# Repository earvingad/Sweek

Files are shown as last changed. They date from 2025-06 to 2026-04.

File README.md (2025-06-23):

# Sweek
Sweek is a Ferris/sweep inspired, 36 keys split keyboard.

The K in the name comes from it using [KMK](https://github.com/KMKfw/kmk_firmware).
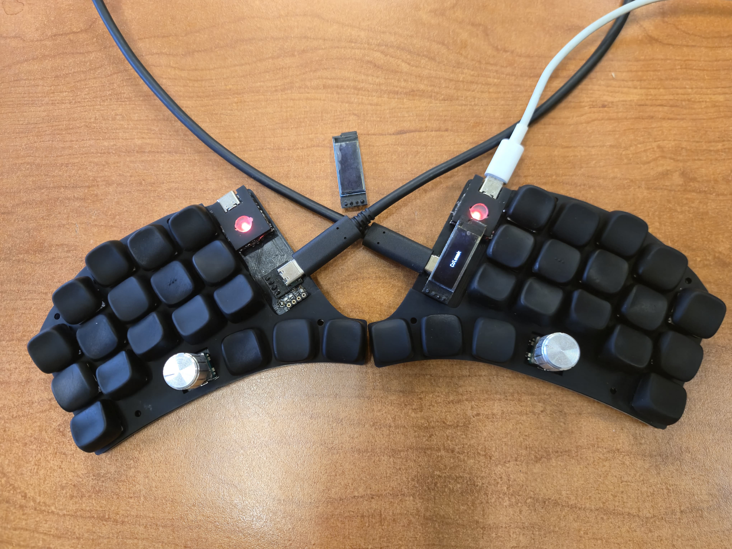
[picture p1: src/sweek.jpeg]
sweek

It features:
- Reversible PCB with through holes diodes for easy soldering.
- RP2040 as MCU.
- Support for MX, choc V1/V2 and Redragon low profile switches (I only tested MX and Redragon LP).
- EC11 encoders and oled displays.
- Communication is through USB-C (using a pair of small USB-C boards available, since I wanted as easiest to solder as possible).
- There is also a diodeless version.

Please see the [Building guide for v1.0.1](./src/buildingguide_v101.org).

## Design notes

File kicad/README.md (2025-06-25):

Here you can find the Kicad files to export the gerbers for production in JLCPCB or similar.

There are two versions:
1. sweek_rdmxchoc - Contains the files for the PCB that includes encoders and oled 128x32
2. sweek_rdmxchoc_diodless - Diodeless version, without encoders and oled.

Please see the [Building guide](/src/buildingguide_v101.org).

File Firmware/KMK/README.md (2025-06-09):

# Intructions for KMK

1. [Install Circuitpython](https://learn.adafruit.com/welcome-to-circuitpython/installing-circuitpython) to your RP2040-zero and then [KMK](https://github.com/KMKfw/kmk_firmware/blob/main/docs/en/Getting_Started.md#tldr-quick-start-guide). 
2. Rename the drives as `SWEEKL` and `SWEEKR`, respectively. Follow [this guide](https://learn.adafruit.com/welcome-to-circuitpython/renaming-circuitpy) to learn how to do it.
3. Follow the [Preparation guide for Display in KMK](https://github.com/KMKfw/kmk_firmware/blob/main/docs/en/Display.md#preparation) for the required libraries for the SSD1306 oled display.
4. Download the `neopixel.py` or `neopixel.mpy` from [here](https://github.com/adafruit/Adafruit_CircuitPython_NeoPixel/releases) and place it inside the `lib` folder of each RP2040-zero.
5. Copy the `code.py` to each RP2040-zero. It will automatically detect which half is which.

Enjoy!

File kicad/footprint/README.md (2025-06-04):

Custom footprint to support MX, choc V1/V2 and redragon Low Profile.

Created using:
- [Joe Scotto](https://github.com/joe-scotto/scottokeebs/tree/main/Extras/ScottoKicad) footprints for MX and choc and
- [rgoulter](https://github.com/rgoulter/keyboard-labs/blob/master/pcb/ProjectLocal.pretty/SW_Redragon_LowProfile_PCB_1.00u.kicad_mod) footprint for redragon Low Profile.

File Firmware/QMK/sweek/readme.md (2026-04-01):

# sweek

sweek

Sweek is a Ferris/sweep inspired, 36 keys split keyboard with encoders and OLED screens (although I have not configured OLED screens for QMK).

* Keyboard Maintainer: [earvingad](https://github.com/earvingad)
* Hardware Supported: [sweek](https://github.com/earvingad/sweek)

Compile with vial support and flash with EE_HANDS

    make sweek:vial:uf2-split-left

And then righ side:

    make sweek:vial:uf2-split-right

See the [build environment setup](https://docs.qmk.fm/#/getting_started_build_tools) and the [make instructions](https://docs.qmk.fm/#/getting_started_make_guide) for more information. Brand new to QMK? Start with our [Complete Newbs Guide](https://docs.qmk.fm/#/newbs).

## Bootloader

Enter the bootloader in 3 ways:

* **Physical reset button**: Press quickly twice the reset button from the RP2040-zero.
* **Bootmagic reset**: Hold down the key at (0,0) in the matrix (usually the top left key or Escape) and plug in the keyboard
* **Keycode in layout**: Press the key mapped to `QK_BOOT` if it is available

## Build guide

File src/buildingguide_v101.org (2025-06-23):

#+title: Sweek v1.0.1 building guide

Please do not consider this board suitable for beginners, you need some experience soldering as you will need to solder some jumpers. However, it is not difficult to solder. I recommend using enameled wire of 0.2-0.5 mm.

The board is reversible, but it needs to solder some jumpers for both sides to work correctly. I tried to avoid pin remapping in software as much as possible, but this means that jumpers need to be soldered differently in each side.

* Sweek with encoders and oled
** USB-C board, encoder and oled display
The communication is through an USB-C board like [[https://es.aliexpress.com/item/1005005187678366.html][this]]. The reason I chose this is because it is cheap and it is easy to solder.

Encoder height recommendation:

- For low profile switches use 10-12 mm tall EC11 encoders.
- For MX switches use 15 mm tall EC11 encoders.

Follow this picture as reference of how jumpers must solder. ALWAYS SOLDER FROM THE BACK OF THE PCB:

Use insulated tape to cover wires when needed. For example, in the right side, I would solder first Rx to D- and in order to avoid shorts, I would cover the jumper (Rx to D-) with insulation tape and then proceed to solder the 5.5 V jumper.
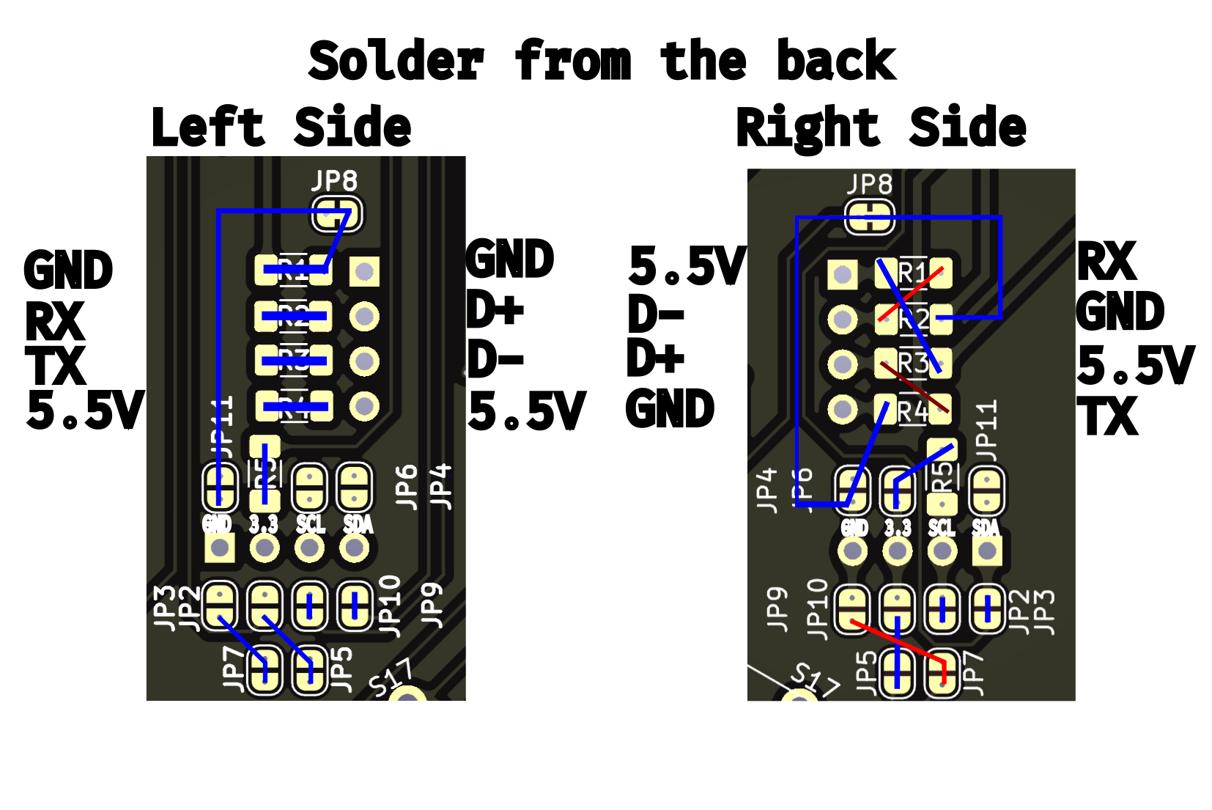
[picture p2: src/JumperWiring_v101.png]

** 3.3v ONLY ON THE RIGHT SIDE
Solder the jumper located on the MCU position (JP1). This will serve to route 3.3 V to the right oled display.
#+ATTR_HTML: :width 300px
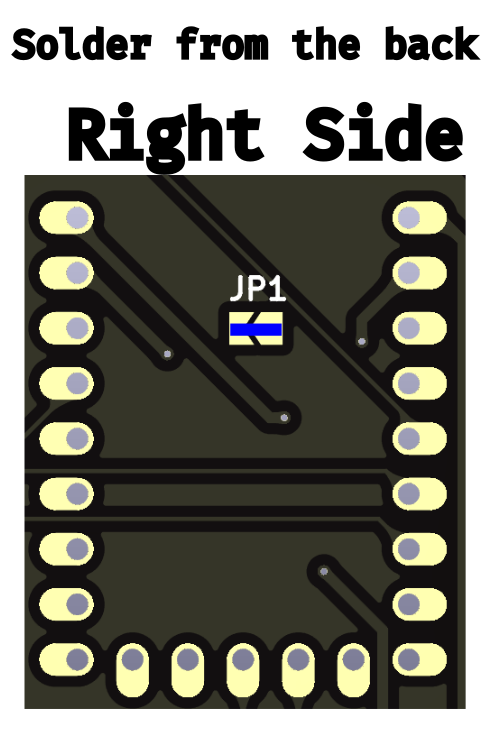
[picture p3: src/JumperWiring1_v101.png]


** MCU
In both sides, the RP2040 must always be facing up. This is how the PCB was designed in order to have the RGB led available as layer indicator and easy access to buttons for hard reset and enter boot mode.

Please be aware that pin 2 (GP2) is never in use, so *DO NOT SOLDER PIN 2 (GP2) OF THE RP2040 TO THE BOARD*.
** Diodes orientation
Solder diodes to the board, you can choose between SMD diodes (SOD-123) or through hole diodes, just make sure they are 1N4148

The board has printed the orientation, but take the following picture as reference. Ignore the MCU (I know it is not a RP2040 in the picture, I was experimenting).
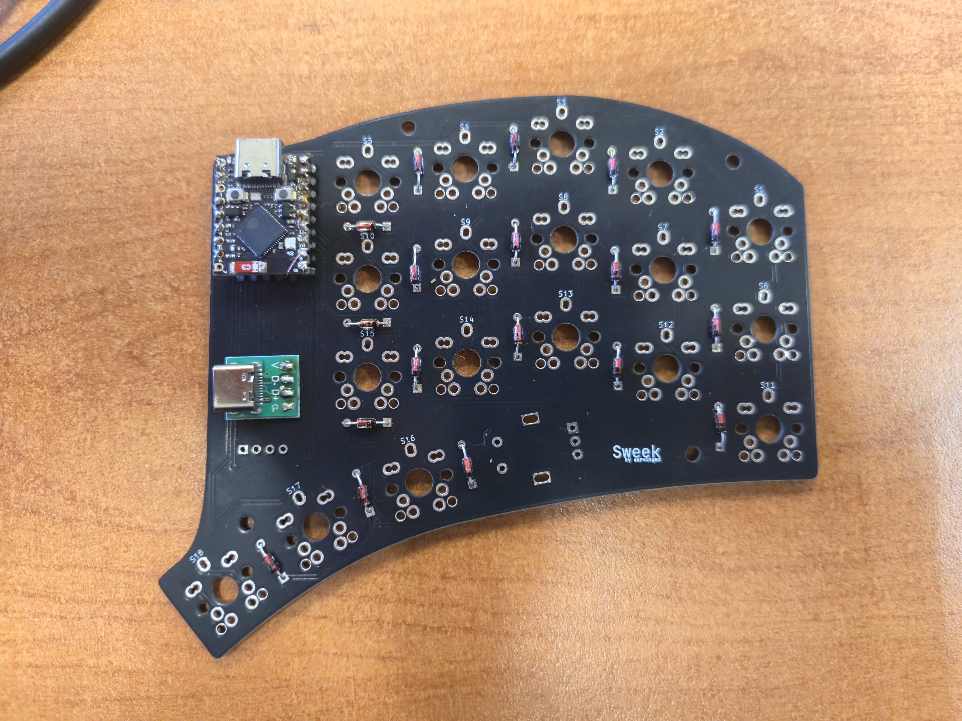
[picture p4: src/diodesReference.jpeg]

** Pin mapping
This is how pins are assigned to the columns and rows for each side:

Left side:
- Rows: GP29, GP28, GP27, GP26.
- Columns: GP3, GP4, GP5, GP6, GP7.

Right side:
- Rows: GP3, GP4, GP5, GP6.
- Columns: GP29, GP28, GP27, GP26, GP15.

Both sides:
- Encoder: GP10, GP9
- Encoder switch: GP11

Both sides:
- Oled SDA: GP12
- Oled SCL: GP13
* Diodeless version
** USB-C board
Solder according to the following picture.
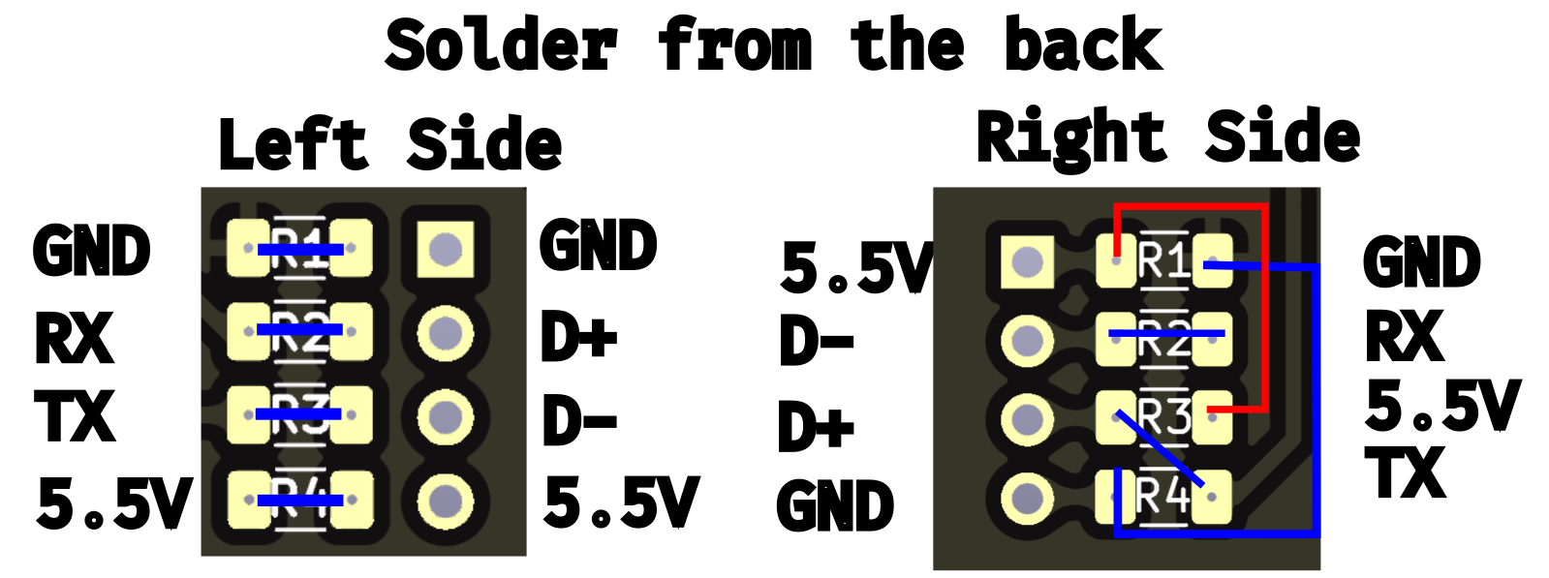
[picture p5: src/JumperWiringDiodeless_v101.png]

** JUMPERS
Compared to v1.0.0, in the new v1.0.1, the GND net is now part of the fill zone. In order to make it possible, two additional jumpers for GND and GP1 were added. Solder the GND and GP1 (RX) jumpers accordingly to each side.

ONLY ON RIGHT SIDE, solder the jumper located on the MCU position (JP1). This route the pin 2 (GP2) to switch-18 on the right side.
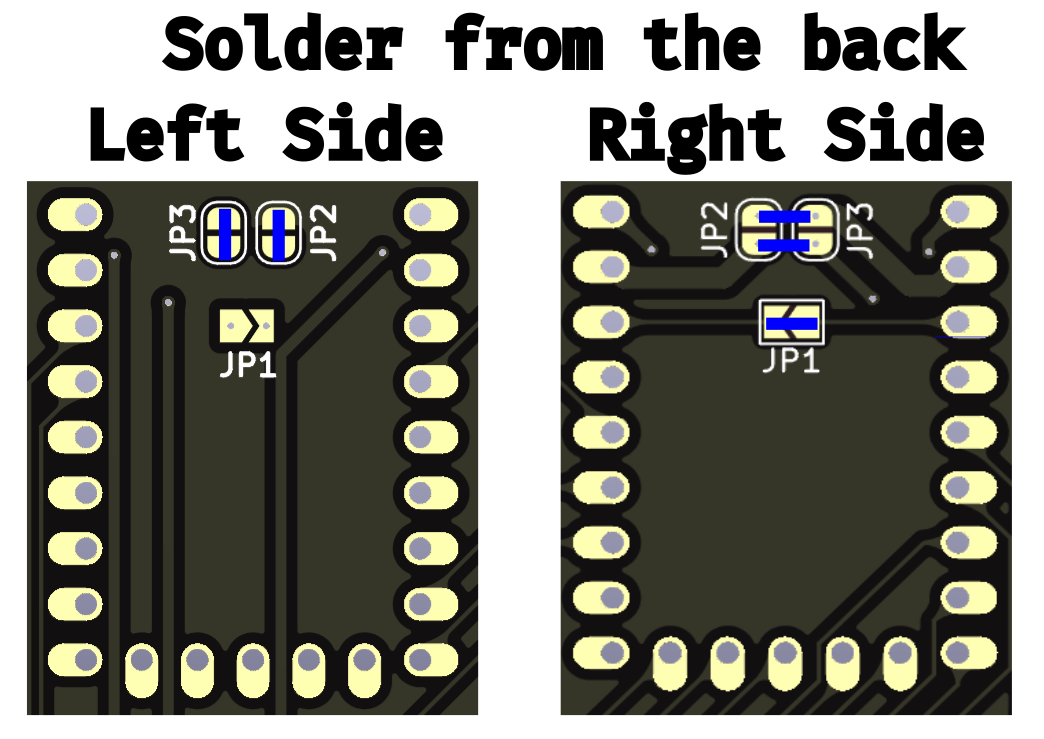
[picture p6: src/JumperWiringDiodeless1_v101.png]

** MCU
Solder every pin of the MCU (RP2040) to the board, except the 3.3 V pin.
** Pin to switch mapping
In both sides GP0 (TX) and GP1 (RX) are reserved for communication.

| Left side | Pin  | Switch | Right side | Pin  | Switch |
|-----------+------+--------+------------+------+--------|
|           | GP29 | S1     |            | GP3  | S1     |
|           | GP28 | S2     |            | GP4  | S2     |
|           | GP27 | S3     |            | GP5  | S3     |
|           | GP26 | S4     |            | GP6  | S4     |
|           | GP15 | S5     |            | GP7  | S5     |
|           | GP14 | S6     |            | GP8  | S6     |
|           | GP13 | S7     |            | GP9  | S7     |
|           | GP12 | S8     |            | GP10 | S8     |
|           | GP11 | S9     |            | GP11 | S9     |
|           | GP10 | S10    |            | GP12 | S10    |
|           | GP9  | S11    |            | GP13 | S11    |
|           | GP8  | S12    |            | GP14 | S12    |
|           | GP7  | S13    |            | GP15 | S13    |
|           | GP6  | S14    |            | GP26 | S14    |
|           | GP5  | S15    |            | GP27 | S15    |
|           | GP4  | S16    |            | GP28 | S16    |
|           | GP3  | S17    |            | GP29 | S17    |
|           | GP2  | S18    |            | GP2  | S18    |

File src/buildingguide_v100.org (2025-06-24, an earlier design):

#+title: Sweek v1.0.0 building guide

Please do not consider this board suitable for beginners, you need some experience soldering as you will need to solder some jumpers. However, it is not difficult to solder. I recommend using enameled wire of 0.2-0.5 mm.

The board is reversible, but it needs to solder some jumpers for both sides to work correctly. I tried to avoid pin remapping in software as much as possible, but this means that jumpers need to be soldered differently in each side.

* Sweek with encoders and oled
** USB-C board, encoder and oled display
The communication is through an USB-C board like [[https://es.aliexpress.com/item/1005005187678366.html][this]]. The reason I chose this is because it is cheap and it is easy to solder.

Encoder height recommendation:
- For low profile switches use 10-12 mm tall EC11 encoders.
- For MX switches use 15 mm tall EC11 encoders.

Follow this picture as reference of how jumpers must solder:

Use insulated tape to cover wires when needed. For example, in the right side, I would solder first Rx to D- and in order to avoid shorts, I would cover the jumper (Rx to D-) with insulation tape and then proceed to solder the 5.5 V jumper.
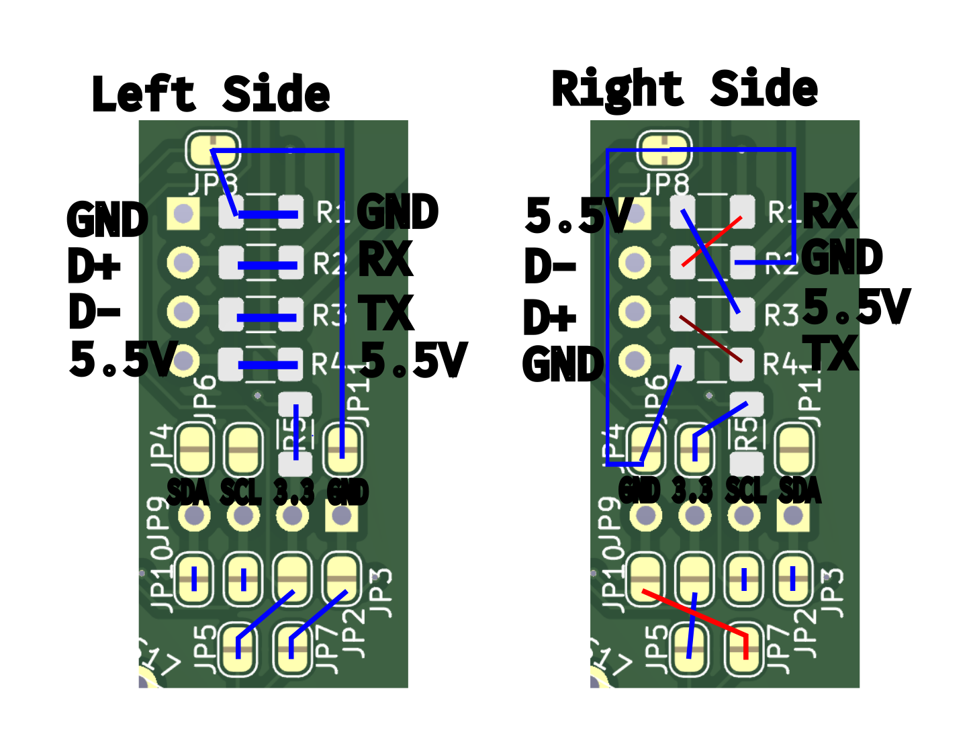
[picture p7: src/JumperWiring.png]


** 3.3v ONLY ON THE RIGHT SIDE
Solder the jumper located on the MCU position (JP1). This will serve to route 3.3 V to the right oled display.
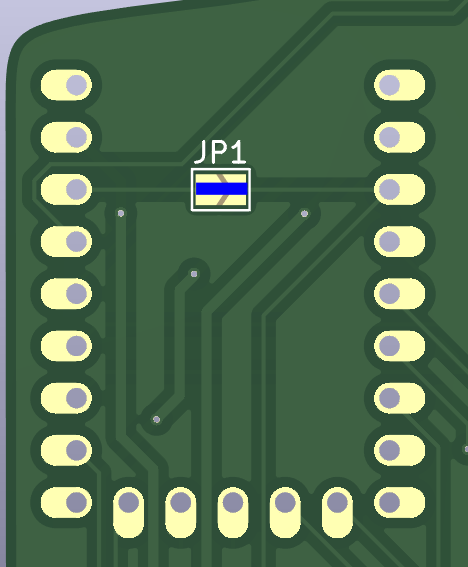
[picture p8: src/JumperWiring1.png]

** MCU
In both sides, the RP2040 must always be facing up. This is how the PCB was designed in order to have the RGB led available as layer indicator and easy access to buttons for hard reset and enter boot mode.

Please be aware that pin 2 (GP2) is never in use, so *DO NOT SOLDER PIN 2 (GP2) OF THE RP2040 TO THE BOARD*.
** Diodes orientation
Solder diodes to the board. The board has printed the orientation, but take the following picture as reference. Ignore the board (I know it is not a RP2040 in the picture, I was experimenting).

** Pin mapping
This is how pins are assigned to the columns and rows for each side:

Left side:
- Rows: GP29, GP28, GP27, GP26.
- Columns: GP3, GP4, GP5, GP6, GP7.

Right side:
- Rows: GP3, GP4, GP5, GP6.
- Columns: GP29, GP28, GP27, GP26, GP15.

Both sides:
- Encoder: GP10, GP9
- Encoder switch: GP11

Both sides:
- Oled SDA: GP12
- Oled SCL: GP13
* Diodeless version
** JUMPER ONLY ON THE RIGHT SIDE
Solder the jumper located on the MCU position (JP1). This route the pin 2 (GP2) to switch-18 on the right side.

** USB-C board
Solder according to the following picture.
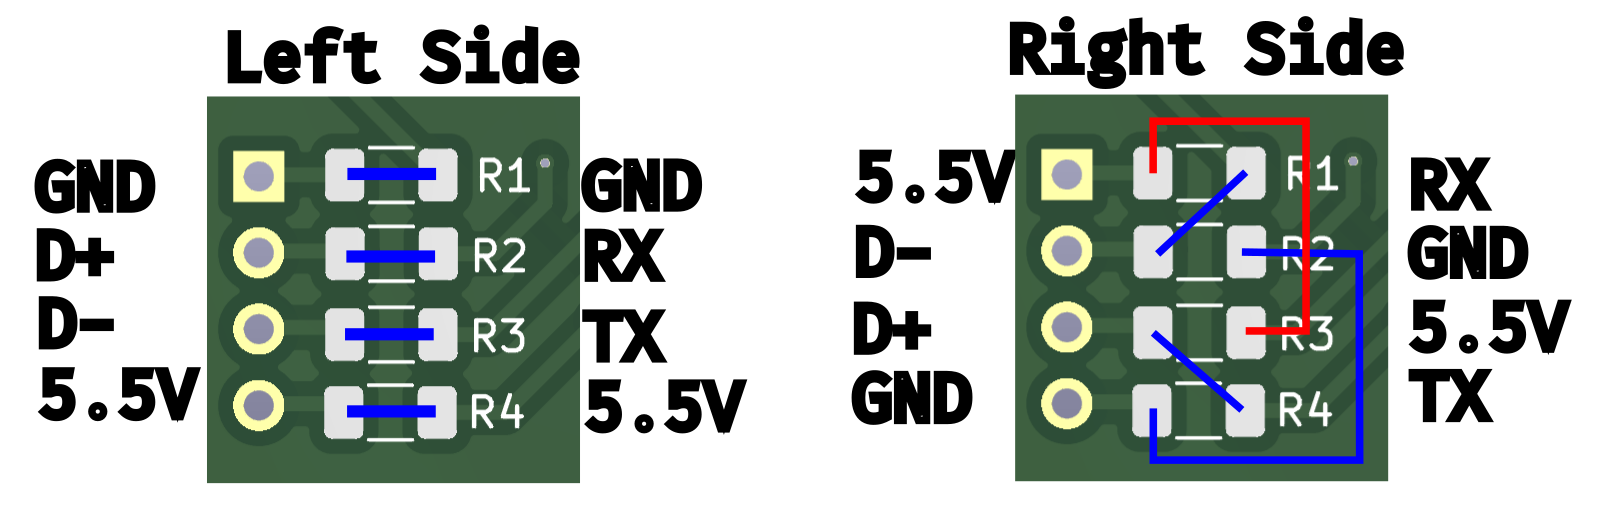
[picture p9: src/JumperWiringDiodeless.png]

** MCU
Solder every pin of the MCU (RP2040) except the 3.3 V pin.
** Pin to switch mapping
In both sides GP0 (TX) and GP1 (RX) are reserved for communication.

| Left side | Pin  | Switch | Right side | Pin  | Switch |
|-----------+------+--------+------------+------+--------|
|           | GP29 | S1     |            | GP3  | S1     |
|           | GP28 | S2     |            | GP4  | S2     |
|           | GP27 | S3     |            | GP5  | S3     |
|           | GP26 | S4     |            | GP6  | S4     |
|           | GP15 | S5     |            | GP7  | S5     |
|           | GP14 | S6     |            | GP8  | S6     |
|           | GP13 | S7     |            | GP9  | S7     |
|           | GP12 | S8     |            | GP10 | S8     |
|           | GP11 | S9     |            | GP11 | S9     |
|           | GP10 | S10    |            | GP12 | S10    |
|           | GP9  | S11    |            | GP13 | S11    |
|           | GP8  | S12    |            | GP14 | S12    |
|           | GP7  | S13    |            | GP15 | S13    |
|           | GP6  | S14    |            | GP26 | S14    |
|           | GP5  | S15    |            | GP27 | S15    |
|           | GP4  | S16    |            | GP28 | S16    |
|           | GP3  | S17    |            | GP29 | S17    |
|           | GP2  | S18    |            | GP2  | S18    |

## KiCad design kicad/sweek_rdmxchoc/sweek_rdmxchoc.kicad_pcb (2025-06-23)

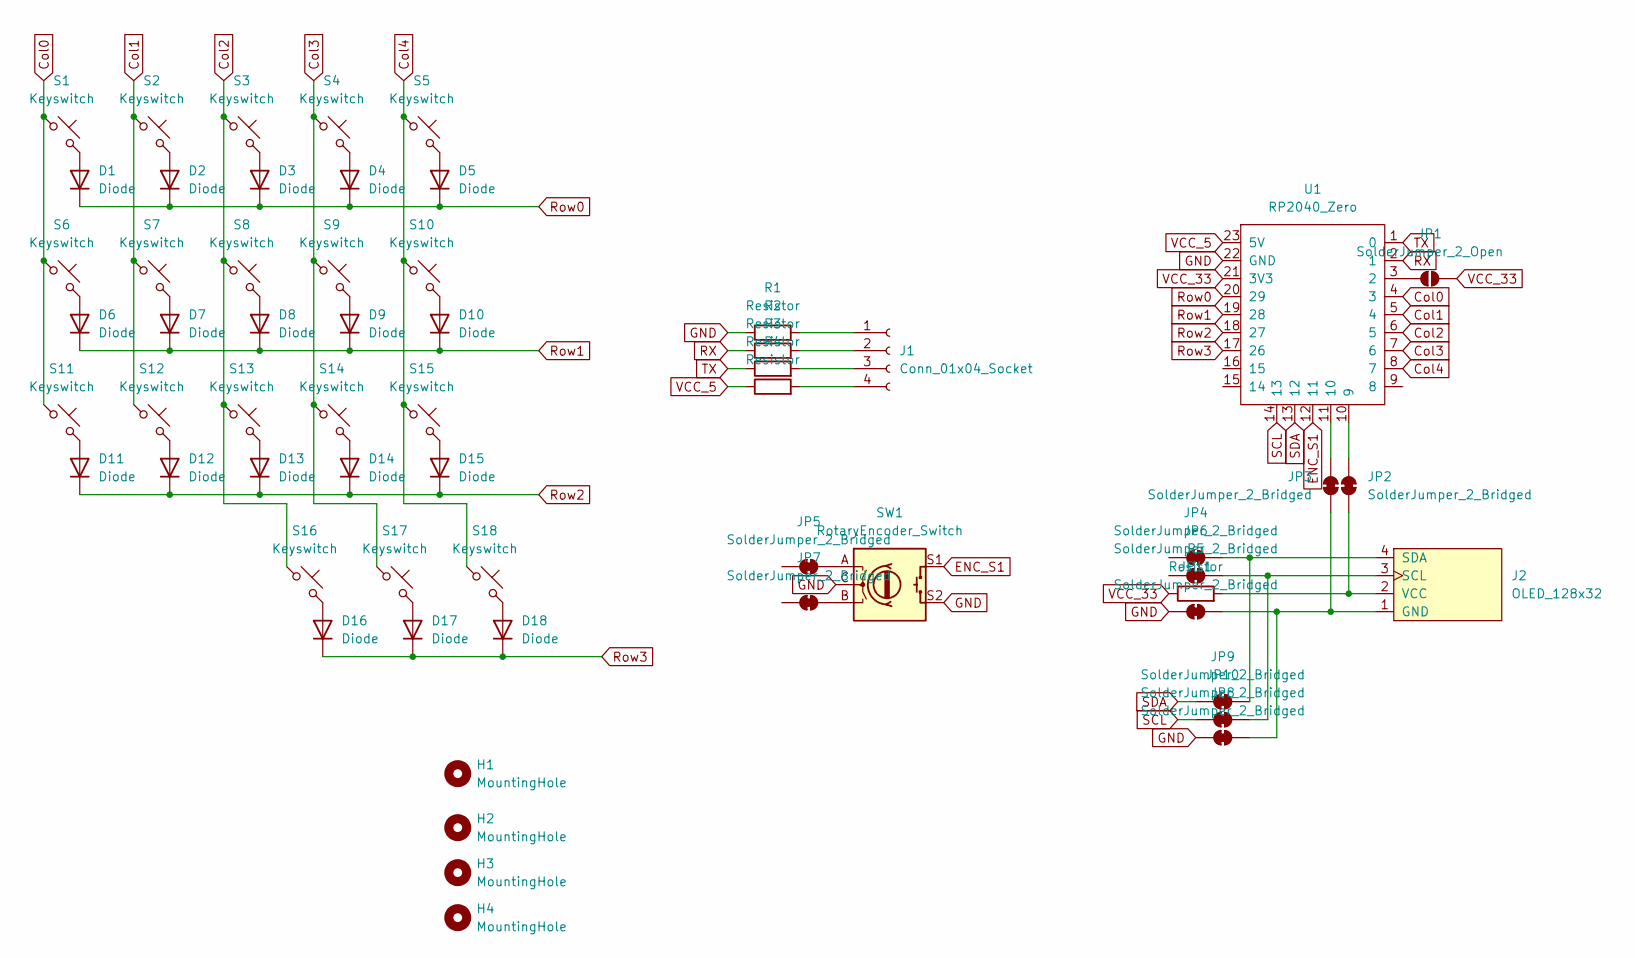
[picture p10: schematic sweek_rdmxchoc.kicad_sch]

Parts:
D1, D2, D3, D4, D5, D6, D7, D8, D9, D10, D11, D12, D13, D14, D15, D16, D17, D18: Diode; Diode_DO-35_SOD-123
H1, H2, H3, H4: MountingHole; MountingHole_2.7mm_M2.5
J1: Conn_01x04_Socket; USB_C_board
J2: OLED_128x32
JP1: SolderJumper_2_Open; SolderJumper-2_P1.3mm_Open_TrianglePad1.0x1.5mm_custom
JP2, JP3, JP4, JP5, JP6, JP7, JP9, JP10, JP11: SolderJumper_2_Bridged; SolderJumper-2_P1.3mm_Open_RoundedPad1.0x1.5mm_custom
JP8: SolderJumper_2_Bridged; SolderJumper-2_P1.3mm_Bridged_RoundedPad1.0x1.5mm_custom
R1, R2, R3, R4, R5: Resistor; R_1206_3216Metric_Pad1.30x1.75mm_custom
S1, S2, S3, S4, S5, S6, S7, S8, S9, S10, S11, S12, S13, S14, S15, S16, S17, S18: Keyswitch; RD_MX_Choc_V1V2_1.00u
SW1: RotaryEncoder_Switch; RotaryEncoder_Alps_EC11E-Switch_Vertical_H20mm
U1: RP2040_Zero

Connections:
Col0: S1.1, S6.1, S11.1, U1.4 (3)
Col1: S2.1, S7.1, S12.1, U1.5 (4)
Col2: S3.1, S8.1, S13.1, S16.1, U1.6 (5)
Col3: S4.1, S9.1, S14.1, S17.1, U1.7 (6)
Col4: S5.1, S10.1, S15.1, S18.1, U1.8 (7)
ENC_S1: SW1.S1, U1.12 (11)
GND: JP8.2 (B), JP11.2 (B), R1.1, SW1.C, SW1.S2, U1.22 (GND)
unnamed: D1.2 (A), S1.2
unnamed: D2.2 (A), S2.2
unnamed: D3.2 (A), S3.2
unnamed: D4.2 (A), S4.2
unnamed: D5.2 (A), S5.2
unnamed: D6.2 (A), S6.2
unnamed: D7.2 (A), S7.2
unnamed: D8.2 (A), S8.2
unnamed: D9.2 (A), S9.2
unnamed: D10.2 (A), S10.2
unnamed: D11.2 (A), S11.2
unnamed: D12.2 (A), S12.2
unnamed: D13.2 (A), S13.2
unnamed: D14.2 (A), S14.2
unnamed: D15.2 (A), S15.2
unnamed: D16.2 (A), S16.2
unnamed: D17.2 (A), S17.2
unnamed: D18.2 (A), S18.2
unnamed: J1.1, R1.2
unnamed: J1.2, R2.2
unnamed: J1.3, R3.2
unnamed: J1.4, R4.2
unnamed: J2.1 (GND), JP3.1 (A), JP8.1 (A), JP11.1 (A)
unnamed: J2.3 (SCL), JP6.1 (A), JP10.2 (B)
unnamed: J2.4 (SDA), JP4.2 (B), JP9.2 (B)
unnamed: J2.2 (VCC), JP2.1 (A), R5.2
unnamed: JP1.1 (A), U1.3 (2)
unnamed: JP2.2 (B), U1.10 (9)
unnamed: JP3.2 (B), U1.11 (10)
unnamed: JP5.2 (B), SW1.A
unnamed: JP7.2 (B), SW1.B
RX: R2.1, U1.2 (1)
Row0: D1.1 (K), D2.1 (K), D3.1 (K), D4.1 (K), D5.1 (K), U1.20 (29)
Row1: D6.1 (K), D7.1 (K), D8.1 (K), D9.1 (K), D10.1 (K), U1.19 (28)
Row2: D11.1 (K), D12.1 (K), D13.1 (K), D14.1 (K), D15.1 (K), U1.18 (27)
Row3: D16.1 (K), D17.1 (K), D18.1 (K), U1.17 (26)
SCL: JP10.1 (A), U1.14 (13)
SDA: JP9.1 (A), U1.13 (12)
TX: R3.1, U1.1 (0)
VCC_5: R4.1, U1.23 (5V)
VCC_33: JP1.2 (B), R5.1, U1.21 (3V3)

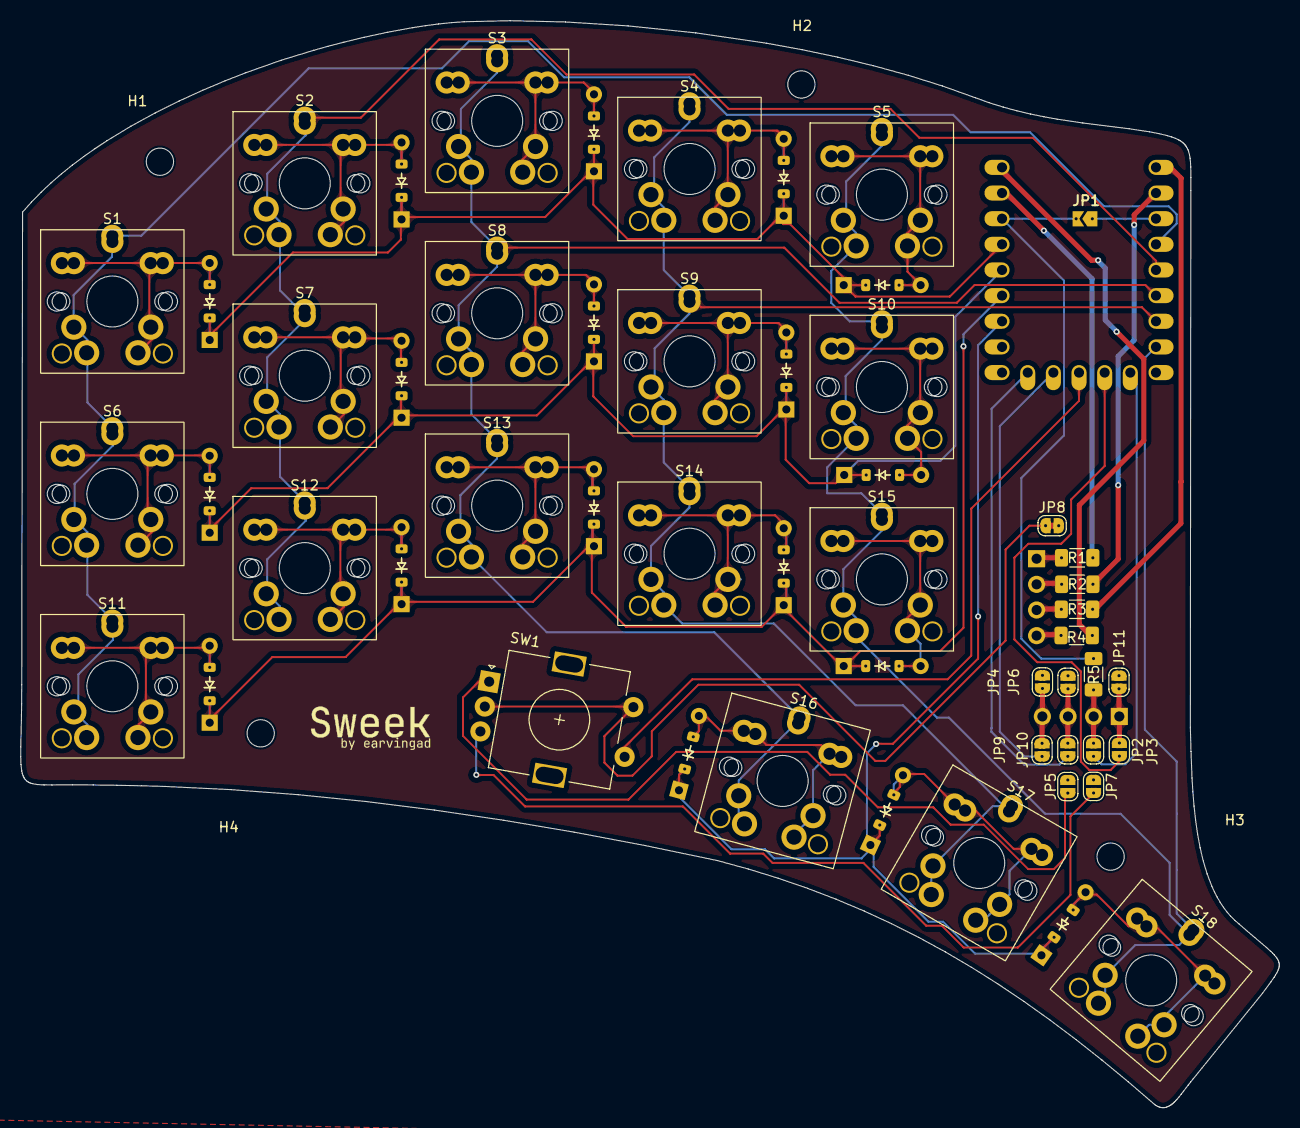
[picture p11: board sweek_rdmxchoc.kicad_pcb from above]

Board: 2 copper layers, 124.6 x 107.6 mm, 60 parts (1 on the bottom side), 48 nets.

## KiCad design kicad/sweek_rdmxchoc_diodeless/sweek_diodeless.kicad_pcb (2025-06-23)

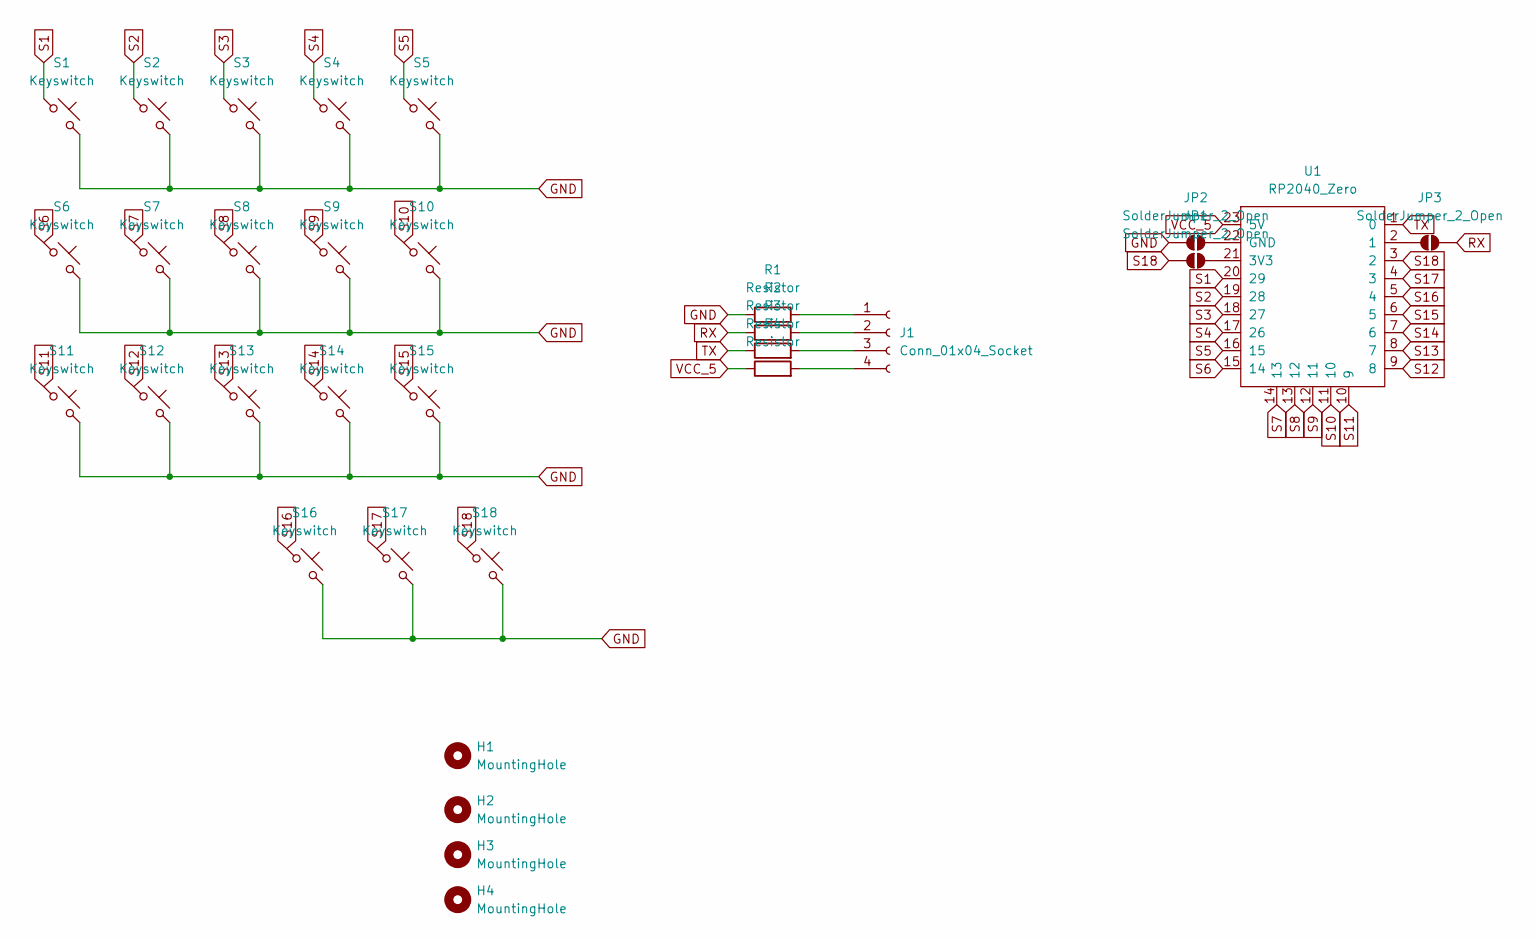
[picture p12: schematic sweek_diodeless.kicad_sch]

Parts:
H1, H2, H3, H4: MountingHole; MountingHole_2.7mm_M2.5
J1: Conn_01x04_Socket; USB_C_board
JP1: SolderJumper_2_Open; SolderJumper-2_P1.3mm_Open_TrianglePad1.0x1.5mm_custom
JP2, JP3: SolderJumper_2_Open; SolderJumper-2_P1.3mm_Open_RoundedPad1.0x1.5mm_custom
R1, R2, R3, R4: Resistor; R_1206_3216Metric_Pad1.30x1.75mm_custom
S1, S2, S3, S4, S5, S6, S7, S8, S9, S10, S11, S12, S13, S14, S15, S16, S17, S18: Keyswitch; RD_MX_Choc_V1V2_1.00u
U1: RP2040_Zero

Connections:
GND: JP2.1 (A), R1.1, S1.2, S2.2, S3.2, S4.2, S5.2, S6.2, S7.2, S8.2, S9.2, S10.2, S11.2, S12.2, S13.2, S14.2, S15.2, S16.2, S17.2, S18.2
unnamed: J1.1, R1.2
unnamed: J1.2, R2.2
unnamed: J1.3, R3.2
unnamed: J1.4, R4.2
unnamed: JP1.2 (B), U1.21 (3V3)
unnamed: JP2.2 (B), U1.22 (GND)
unnamed: JP3.1 (A), U1.2 (1)
RX: JP3.2 (B), R2.1
S1: S1.1, U1.20 (29)
S2: S2.1, U1.19 (28)
S3: S3.1, U1.18 (27)
S4: S4.1, U1.17 (26)
S5: S5.1, U1.16 (15)
S6: S6.1, U1.15 (14)
S7: S7.1, U1.14 (13)
S8: S8.1, U1.13 (12)
S9: S9.1, U1.12 (11)
S10: S10.1, U1.11 (10)
S11: S11.1, U1.10 (9)
S12: S12.1, U1.9 (8)
S13: S13.1, U1.8 (7)
S14: S14.1, U1.7 (6)
S15: S15.1, U1.6 (5)
S16: S16.1, U1.5 (4)
S17: S17.1, U1.4 (3)
S18: JP1.1 (A), S18.1, U1.3 (2)
TX: R3.1, U1.1 (0)
VCC_5: R4.1, U1.23 (5V)

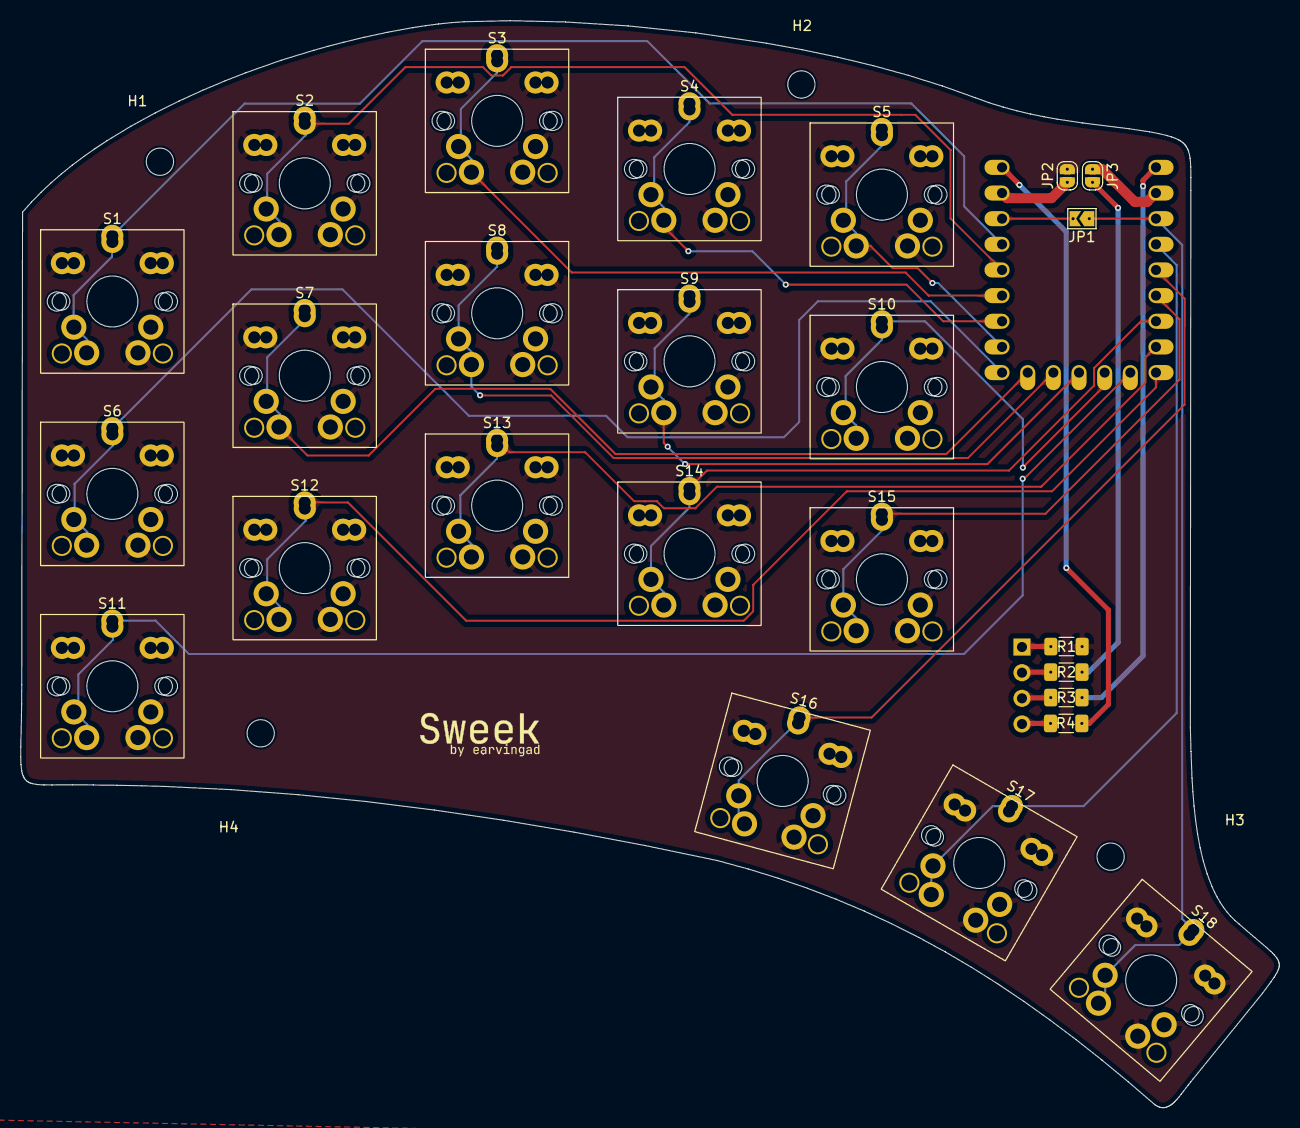
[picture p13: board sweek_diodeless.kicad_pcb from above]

Board: 2 copper layers, 124.6 x 107.6 mm, 31 parts (0 on the bottom side), 29 nets.

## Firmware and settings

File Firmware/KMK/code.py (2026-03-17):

print("Starting sweek.")

import board
from kmk.kmk_keyboard import KMKKeyboard
from kmk.keys import KC
from kmk.scanners import DiodeOrientation
from kmk.scanners.keypad import KeysScanner, MatrixScanner
from kmk.scanners.encoder import RotaryioEncoder
from kmk.modules.mouse_keys import MouseKeys
from kmk.modules.combos import Combos, Chord
from kmk.modules.holdtap import HoldTap
from kmk.modules.sticky_keys import StickyKeys
from kmk.modules.capsword import CapsWord
from kmk.modules.layers import Layers
from kmk.extensions.international import International
from kmk.modules.split import Split, SplitSide, SplitType
from kmk.extensions.media_keys import MediaKeys
from kmk.modules.mouse_jiggler import MouseJiggler
from kmk.modules.sticky_mod import StickyMod

# side = SplitSide.LEFT
# side = SplitSide.RIGHT
from storage import getmount
side = SplitSide.RIGHT if str(getmount('/').label)[-1] == 'R' else SplitSide.LEFT

split = Split(
    split_flip=True,  # If both halves are the same, but flipped, set this True
    split_side=None,  # Sets if this is to SplitSide.LEFT or SplitSide.RIGHT, or use EE hands
    split_type=SplitType.UART,  # Defaults to UART
    split_target_left=False,  # Assumes that left will be the one on USB. Set to False if it will be the right
    uart_interval=20,  # Sets the uarts delay. Lower numbers draw more power
    data_pin=board.GP1,  # The primary data pin to talk to the secondary device with
    data_pin2=board.GP0,  # Second uart pin to allow 2 way communication
    uart_flip=False,  # Reverses the RX and TX pins if both are provided
    use_pio=False,  # Use RP2040 PIO implementation of UART. Required if you want to use other pins than RX/TX
)

if side == SplitSide.RIGHT:
    row_pins = (board.GP3 , board.GP4 , board.GP5 , board.GP6)
    col_pins = (board.GP29, board.GP28, board.GP27, board.GP26, board.GP15)
else:
    row_pins = (board.GP29, board.GP28, board.GP27, board.GP26)
    col_pins = (board.GP3 , board.GP4 , board.GP5 , board.GP6, board.GP7)

enca=board.GP10
encb=board.GP9
encs=[board.GP11]

class MyKeyboard(KMKKeyboard):
    def __init__(self):
        super().__init__()
        # create and register the scanner
        self.matrix = [
            MatrixScanner(
            # required arguments:
            row_pins=row_pins,
            column_pins=col_pins,
                ),
            RotaryioEncoder(
            # require argument:
            pin_a=enca,
            pin_b=encb,
            divisor=4,
                ),
            KeysScanner(
            # require argument:
            pins=encs,
            value_when_pressed=False,
            pull=True,
                ),
        ]
        self.coord_mapping = [
                0, 1, 2, 3, 4,   27, 26, 25, 24, 23,
                5, 6, 7, 8, 9,   32, 31, 30, 29, 28,
                10,11,12,13,14,  37, 36, 35, 34, 33,
                15,16,17,18,19,  42, 41, 40, 39, 38,
                      20,21,22,  45, 44, 43 ]

keyboard = MyKeyboard()
keyboard.diode_orientation = DiodeOrientation.COL2ROW

mousekeys = MouseKeys(
    max_speed = 30,
    acc_interval = 20, # Delta ms to apply acceleration
    move_step = 1
)

combos = Combos()
holdtap = HoldTap()
holdtap.tap_time = 200
sticky_keys = StickyKeys(release_after=500)
caps_word = CapsWord()
sticky_mod = StickyMod()
keyboard.modules.append(Layers())
keyboard.modules.append(combos)
keyboard.modules.append(holdtap)
keyboard.modules.append(mousekeys)
keyboard.modules.append(caps_word)
keyboard.modules.append(sticky_keys)
keyboard.extensions.append(International())
keyboard.extensions.append(MediaKeys())
keyboard.modules.append(jiggler)
keyboard.modules.append(sticky_mod)
keyboard.modules.append(split)

try:
    import busio
    from kmk.extensions.display import Display, TextEntry
    # For SSD1306
    from kmk.extensions.display.ssd1306 import SSD1306
    # Replace SCL and SDA according to your hardware configuration.
    i2c_bus = busio.I2C(board.GP13, board.GP12)
    driver = SSD1306(
        # Mandatory:
        i2c=i2c_bus,
        # Optional:
        device_address=0x3C,
        )
    display = Display(
        display=driver,
        entries=[
            TextEntry(text="Colemak" , x=40, y=13, layer=0),
            TextEntry(text="Mouse"   , x=40, y=13, layer=1),
            TextEntry(text="Numbers" , x=40, y=13, layer=2),
            TextEntry(text="Function", x=40, y=13, layer=3),
            TextEntry(text="Symbols" , x=40, y=13, layer=4),
            TextEntry(text="Extras"  , x=40, y=13, layer=5),
            TextEntry(text=" Sweek " , x=40, y=13, inverted=True, layer=6),
        ],
        #Optional width argument. Default is 128.
        width=128,
        height=32,
    )
    keyboard.extensions.append(display)
except:
    pass

import neopixel
pixel_pin = board.GP16
num_pixels = 1

pixels = neopixel.NeoPixel(pixel_pin, num_pixels, brightness=0.3, auto_write=False)
RED = (55, 0, 0)
GREEN = (0, 55, 0)
BLUE = (0, 0, 55)
YELLOW = (55, 55, 0)
CYAN = (0, 55, 55)
PURPLE = (55, 0, 55)
WHITE = (55, 55, 55)

def on_layer_change(self, layer):
    if layer == 0:
        pixels.fill(RED)
    elif layer == 1:
        pixels.fill(BLUE)
    elif layer == 2:
        pixels.fill(GREEN)
    elif layer == 3:
        pixels.fill(WHITE)
    elif layer == 4:
        pixels.fill(PURPLE)
    elif layer == 5:
        pixels.fill(CYAN)
    elif layer == 6:
        pixels.fill(CYAN)
    # update the LEDs manually if no animation is active:
    pixels.show()

class RGBLayers(Layers):
    def during_bootup(self, sandbox):
        layer=keyboard.active_layers[0]
        on_layer_change(self, layer)

    def activate_layer(self, keyboard, layer, idx=None):
        super().activate_layer(keyboard, layer, idx)
        on_layer_change(self, layer)

    def deactivate_layer(self, keyboard, layer):
        super().deactivate_layer(keyboard, layer)
        layer=keyboard.active_layers[0]
        on_layer_change(self, layer)

keyboard.modules.append(RGBLayers())

SPC_ALT  = KC.HT(KC.SPC , KC.SK(KC.LALT), tap_interrupted=True)
DOT_APP  = KC.HT(KC.DOT , KC.APP        , tap_interrupted=True)
BSPC_ALT = KC.HT(KC.BSPC, KC.RALT       , tap_interrupted=True)

SK_LGUI = KC.SK(KC.LGUI)
SK_LCTL = KC.SK(KC.LCTL)
SK_RALT = KC.SK(KC.RALT)
NXT_WIN = KC.SM(KC.TAB, KC.LALT)
PRV_WIN = KC.SM(KC.TAB, KC.LSFT(KC.LALT))

SK_RSFT = KC.SK(KC.RSFT)
R_L1    = KC.HT(KC.R  , KC.MO(1), tap_interrupted=True)
S_L2    = KC.HT(KC.S  , KC.MO(2), tap_interrupted=True)
T_L3    = KC.HT(KC.T  , KC.MO(3), tap_interrupted=True)
N_L6    = KC.HT(KC.N  , KC.MO(6), tap_interrupted=True)
E_L4    = KC.HT(KC.E  , KC.MO(4), tap_interrupted=True)
ENT_L5  = KC.HT(KC.ENT, KC.MO(5))
ESC_L5  = KC.HT(KC.ESC, KC.MO(5))

ALT_F4  = KC.LALT(KC.F4)
CTL_ALT = KC.LCTL(KC.LALT)
CTLALTD = KC.LCTL(KC.LALT(KC.DEL))
CTLSFTT = KC.LCTL(KC.LSFT(KC.T))
LSFTDEL = KC.LSFT(KC.DEL)

_______ = KC.TRNS
XXXXXXX = KC.NO

combos.combos = [
    Chord((KC.W, KC.F), KC.TAB),
    Chord((KC.F, KC.P), KC.CW),
    Chord((KC.O, KC.Y), KC.DEL),
    Chord((KC.O, KC.L), KC.LBRC),
    ]

keyboard.keymap =  [
    [ # 0 COLEMAK
        KC.Q    , KC.W    , KC.F    , KC.P    , KC.G   ,              KC.J     , KC.L      , KC.O      , KC.Y      , KC.SCLN ,
        KC.A    , R_L1    , S_L2    , T_L3    , KC.D   ,              KC.H     , N_L6      , E_L4      , KC.I      , KC.U    ,
        KC.Z    , KC.X    , KC.C    , KC.V    , KC.B   ,              KC.K     , KC.M      , KC.COMMA  , DOT_APP   , KC.SLSH ,
        XXXXXXX , XXXXXXX , KC.LCTL , SPC_ALT , ESC_L5 ,              ENT_L5   , BSPC_ALT  , SK_RSFT   , XXXXXXX   , XXXXXXX ,
                            KC.DOWN , KC.UP   , KC.ENT ,              KC.ENT   , KC.LEFT   , KC.RIGHT  ,
    ],
    [ # 1 Mouse
        _______ , _______ , _______ , _______ , _______ ,             _______  , KC.MB_LMB , KC.MW_UP  , KC.MB_RMB , _______  ,
        _______ , _______ , KC.MB_LMB,_______ ,KC.MB_RMB,             _______  , KC.MS_LT  , KC.MS_DN  , KC.MS_UP  , KC.MS_RT ,
        _______ , _______ , _______ , _______ , _______ ,             _______  , KC.MB_MMB , KC.MW_DN  , _______   , _______  ,
        XXXXXXX , XXXXXXX , _______ , KC.SPC  , _______ ,             _______  , _______   , _______   , XXXXXXX   , XXXXXXX  ,
                           KC.LEFT  , KC.RIGHT, _______ ,             _______  , KC.LSFT(KC.TAB) , KC.TAB,
    ],
    [ # 2 Right Numbers/Shift symbols
        _______ , KC.UP   , _______ , _______ , _______ ,             KC.PPLS   , KC.N7     , KC.N8     , KC.N9    , KC.PAST  ,
        _______ , KC.LEFT , _______ , KC.RIGHT, _______ ,             KC.PMNS   , KC.N4     , KC.N5     , KC.N6    , KC. DOT  ,
        _______ , KC.DOWN , _______ , KC.COMMA, _______ ,             KC.N0     , KC.N1     , KC.N2     , KC.N3    , KC.PSLS  ,
        XXXXXXX , XXXXXXX , _______ , _______ , _______ ,             _______   , _______   , _______   , XXXXXXX  , XXXXXXX  ,
                            _______ , _______ , _______ ,             KC.LCTL(KC.N0)        , KC.LCTL(KC.MW_DN) , KC.LCTL(KC.MW_UP)  , 
    ],
    [ # 3 Function keys
        KC.RLD  , PRV_WIN , NXT_WIN , _______ , _______ ,             _______  , KC.F7     , KC.F8     , KC.F9     , KC.F10   ,
        ALT_F4  , CTLSFTT , LSFTDEL , _______ , _______ ,             _______  , KC.F4     , KC.F5     , KC.F6     , KC.F11   ,
        KC.RESET, CTL_ALT , CTLALTD , _______ , _______ ,             _______  , KC.F1     , KC.F2     , KC.F3     , KC.F12   ,
        XXXXXXX , XXXXXXX , _______ , _______ , _______ ,             _______  , _______   , _______   , XXXXXXX   , XXXXXXX  ,
                            _______ , _______ , _______ ,             KC.MPLY  , KC.VOLD   , KC.VOLU   , 
    ],
    [ # 4 Left Symbols
        KC.EXLM , KC.AT   , KC.HASH , KC.DLR  , KC.PERC ,             KC.CIRC  , KC.AMPR   , _______   , KC.GRV    , _______  ,
        KC.MINS , KC.EQL  , KC.LBRC , KC.QUOT , KC.BSLS ,             KC.ASTR  , KC.LPRN   , _______   , KC.RPRN   , _______  ,
        KC.PLUS , KC.UNDS , KC.RBRC , KC.RCBR , KC.PIPE ,             _______  , KC.NUBS   , _______   , _______   , _______  ,
        XXXXXXX , XXXXXXX , _______ , _______ , _______ ,             KC.RCTL  , _______   , _______   , XXXXXXX   , XXXXXXX  ,
         KC.LSFT(KC.LEFT) , KC.LSFT(KC.RIGHT) , _______ ,             _______  , _______   , _______   , 
    ],
    [ # 5 Nav/extras
        KC.CAPS , KC.HOME , KC.PGUP , KC.DEL  , KC.LSFT ,             _______  , _______   , KC.PGUP   ,  KC.HOME  ,  _______     ,
        KC.LEFT , KC.DOWN , KC.UP   , KC.RIGHT, SK_LGUI ,             KC.TG(1) , KC.BSPC   , _______   ,  _______  ,  KC.MJ_START ,
        _______ , KC.END  , KC.PGDN , KC.BSPC , KC.ENT  ,             KC.TG(6) , _______   , KC.PGDN   ,  KC.END   ,  KC.MJ_STOP  ,
        XXXXXXX , XXXXXXX , _______ , _______ , _______ ,             _______  , _______   , _______   ,  XXXXXXX  ,  XXXXXXX     ,
                            _______ , _______ , _______ ,             _______  , KC.DOWN   , KC.UP     , 
    ],
    [ # 6 Free to edit layer
        _______ , _______ , _______ , _______ , _______ ,           _______  , _______ , _______  , _______ , _______  ,
        _______ , _______ , _______ , _______ , _______ ,           _______  , _______ , _______  , _______ , _______  ,
        _______ , _______ , _______ , _______ , _______ ,           _______  , _______ , _______  , _______ , _______  ,
        XXXXXXX , XXXXXXX , _______ , _______ , _______ ,           _______  , _______ , _______ , XXXXXXX  , XXXXXXX  ,
                            _______ , _______ , _______ ,           _______  , _______   , _______   ,
    ],
]

if __name__ == '__main__':
    keyboard.go()

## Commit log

2025-04-14 Sweek svg for laser cut
    Sweek svg for laser cut, made with Inkscape
2025-06-04 Add diodes reference
    Picture for diodes reference orientation.
2025-06-04 Update buildingguide.org
    Added diode reference information
2025-06-04 kicad files for the sweek
    Original version.
    [sweek_rdmxchoc.kicad_pcb, sweek_rdmxchoc.kicad_sch]
2025-06-04 kicad files sweek diodeless version
    kicad files for the sweek diodeless version
    [sweek_diodeless.kicad_pcb, sweek_diodeless.kicad_sch]
2025-06-04 RD_MX_Choc_V1V2 footprint
    Added RD_MX_Choc_V1V2_1.00u kicad footprint. Supports MX, choc V1/V2 and redragon Low Profile switches.
2025-06-09 Update kicad original sweek
    [sweek_rdmxchoc.kicad_pcb]
2025-06-09 Update kicad sweek diodeless
    [sweek_diodeless.kicad_pcb]
2025-06-09 Update buildingguide.org
    Added EC11 encoder height recommendation.
2025-06-23 Update diodeless kicad files for v1.0.1
    Update diodeless kicad files for v1.0.1
    [sweek_diodeless.kicad_pcb, sweek_diodeless.kicad_sch]
2025-06-23 Update sweek kicad files for v1.0.1
    Update sweek kicad files for v1.0.1
    [sweek_rdmxchoc.kicad_pcb, sweek_rdmxchoc.kicad_sch]
2025-06-23 Delete kicad/sweek_rdmxchoc directory
    deletion to correct files wrongly uploaded
    [sweek_diodeless.kicad_pcb, sweek_diodeless.kicad_sch, sweek_rdmxchoc.kicad_pcb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]
2025-06-25 Correct links in kicad folder.
